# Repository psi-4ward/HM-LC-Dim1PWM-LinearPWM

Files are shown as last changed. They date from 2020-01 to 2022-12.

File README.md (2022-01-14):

# HM-LC-Dim1PWM-LinearPWM

**HomeMatic Aktor mit linearer PWM Ausgabe über Optokoppler zum Beschalten von PWM-Dim Eingängen.**

Es gibt eine ganze Reihe [Meanwell-Netzteile](https://www.meanwell-web.com/en-gb/led-drivers/all-technology/all-power-format/all-output-voltage-v/all-output-current-a/all-output-power-w/all-input-voltage-v/all-i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) mit PWM Eingang zum Dimmen welche über diese Schaltung angesteuert und in Homematic eingebunden werden können.

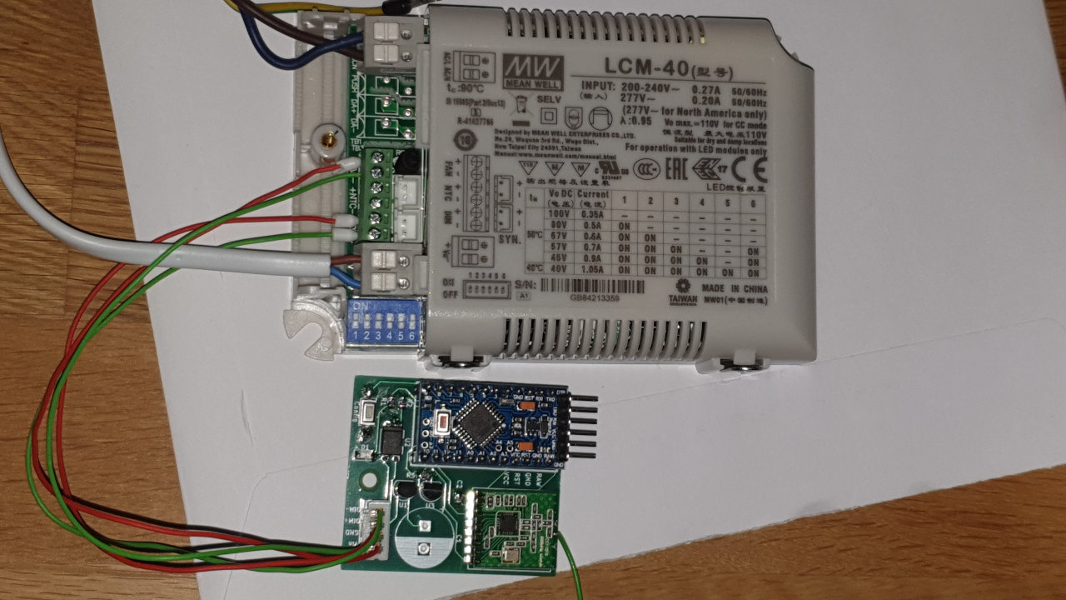
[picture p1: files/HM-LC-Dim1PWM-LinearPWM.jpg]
HM-LC-Dim1PWM-LinearPWM


Es ist darauf zu achten, dass man ein Netzteil mit **3 in 1 dimming** und **dimm-to-off** verwendet:
* 3 in 1: Dimmung über PWM, 0-10V und Potentiometer.
* dimm-to-off: Das Netzteil kann über den DIM-Eingang auch komplett ausgeschaltet werden.

Getestet wurde die Schaltung mit einem Meanwell LCM-40 Netzteil und 30W Konstantstrom-LED-Panel.
Das LCM-40 bietet zusätzlich einen 12V _FAN_ Anschluss worüber den die Schaltung mit Strom versorgt werden kann.

## Hardware

* Arduino Pro Mini 3.3V
* CC1101 Funkmodul
* C1: Elko 2200µF (optional)
* SMD Bauteile Größe 0805
  * C2: Kerko 100nF
  * C3: Kerko 100nF (für L78L05)
  * R1: 1,5kΩ
  * R2, R3: 280Ω
  * R4: 10kΩ
* D1: SMD LED Größe 1206
* SW1: SMD Taster 3x6x2,5mm
* U1: L78L05 Festspannungsregler Größe TO92 (optional)
* U2: Optokoppler PC817
* U3: DS18B20 Temperatursensor (optional)

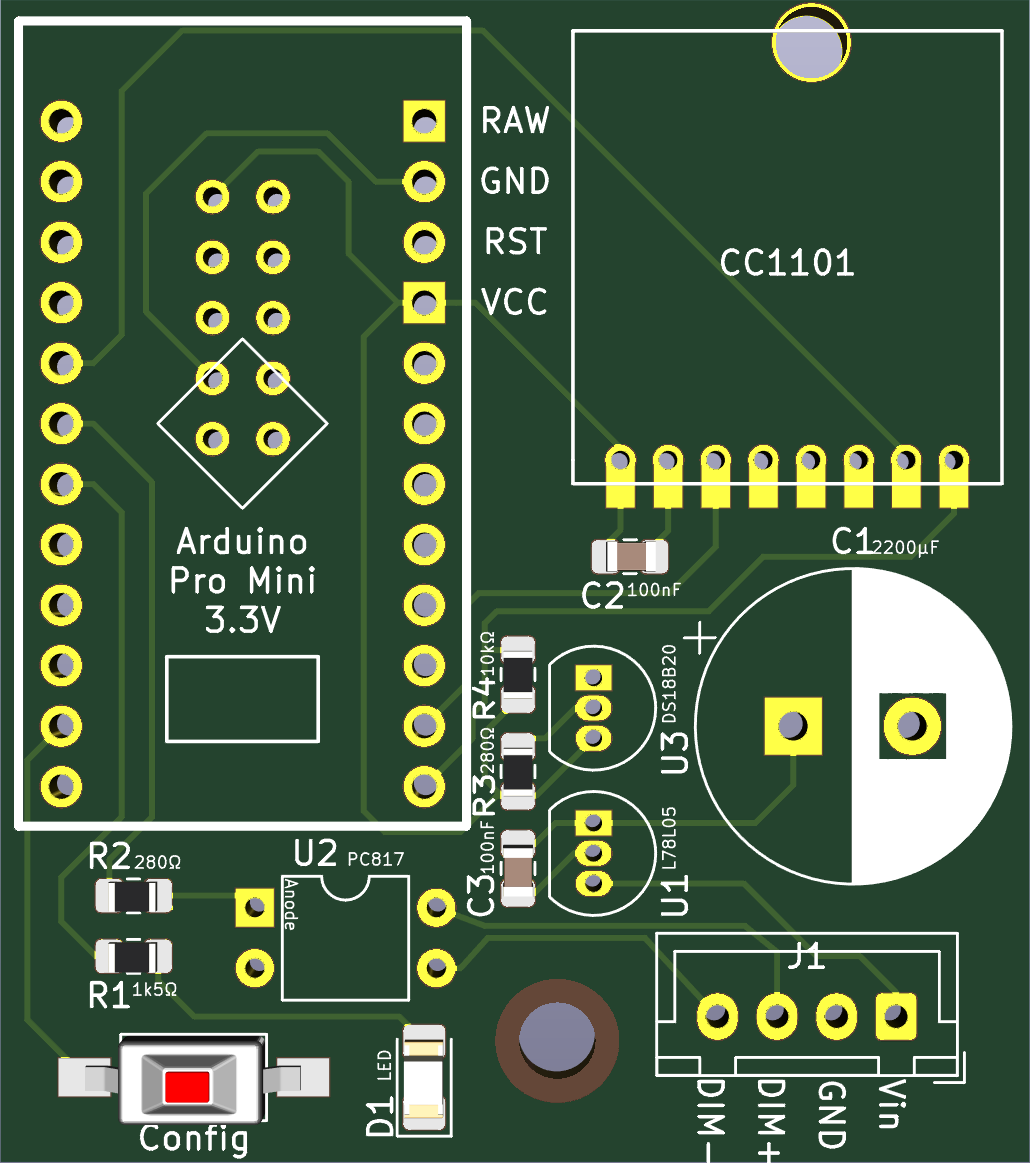
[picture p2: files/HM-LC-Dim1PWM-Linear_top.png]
PCB Top


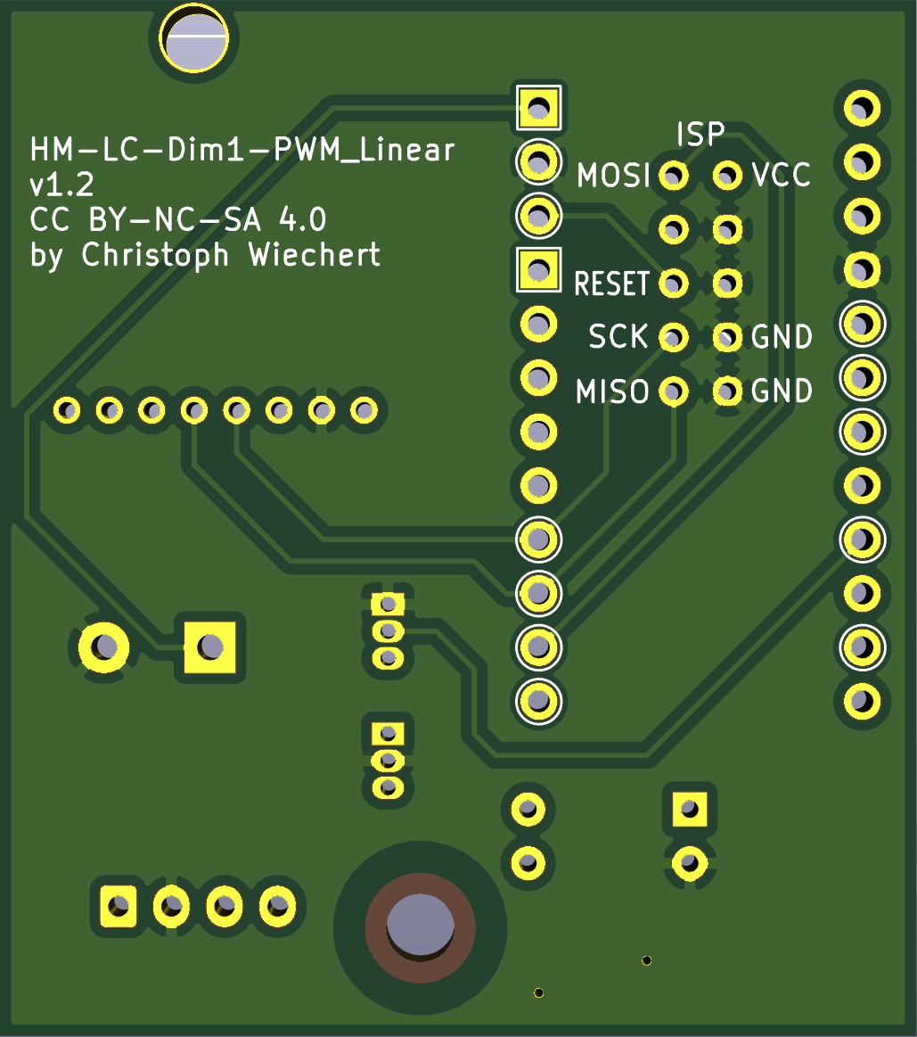
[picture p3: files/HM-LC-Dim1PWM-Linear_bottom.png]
PCB Bottom


## Sketch

Ein [Beispiel-Sketch](./HM-LC-Dim1PWM-LinearPWM.ino) ist im Repo hinterlegt.

Interssant ist die Instanziierung der PWM-Class:

```cpp
DimmerControl<HalType,DimmerType,PWM8<200,true,PWM_INVERSE> > control(sdev);
```

Wobei die Parameter des `PWM8`-Templates:
* `steps`: Anzahl Dimmer-Schritte
* `linear`: Flag um eine lineare Dimmerkurve zu erzeugen
* `inverse`: Dimmerkurve invertieren (nötig da Optokoppler)

**Es empfiehlt sich die Brown-Out-Detection des AVR zu deaktivieren um robuster gegen Spannungseinbrüche zu sein.**

## Case:

* [themaddin](https://www.prusaprinters.org/prints/118561-enclosure-for-homematic-diy-dimmer)  
  

## Changelog

### Version 1.2
* PullUp Widerstand R4 eingefügt 

### Version 1.1
* Markierungen ergänzt

## Lizenz

CreativeCommons BY-NC-SA 4.0

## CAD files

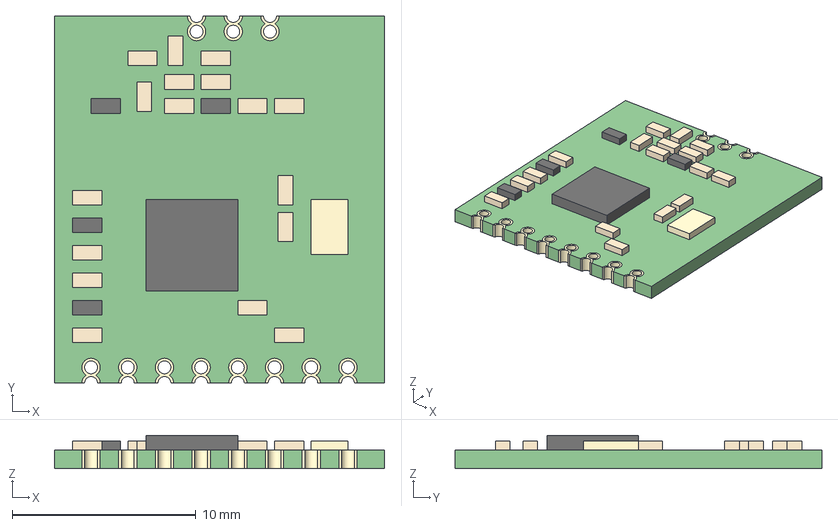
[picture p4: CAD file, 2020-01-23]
KiCad/CC1101_Module.step
18.0 x 20.0 x 1.80 mm
PCB
Parts
Pads

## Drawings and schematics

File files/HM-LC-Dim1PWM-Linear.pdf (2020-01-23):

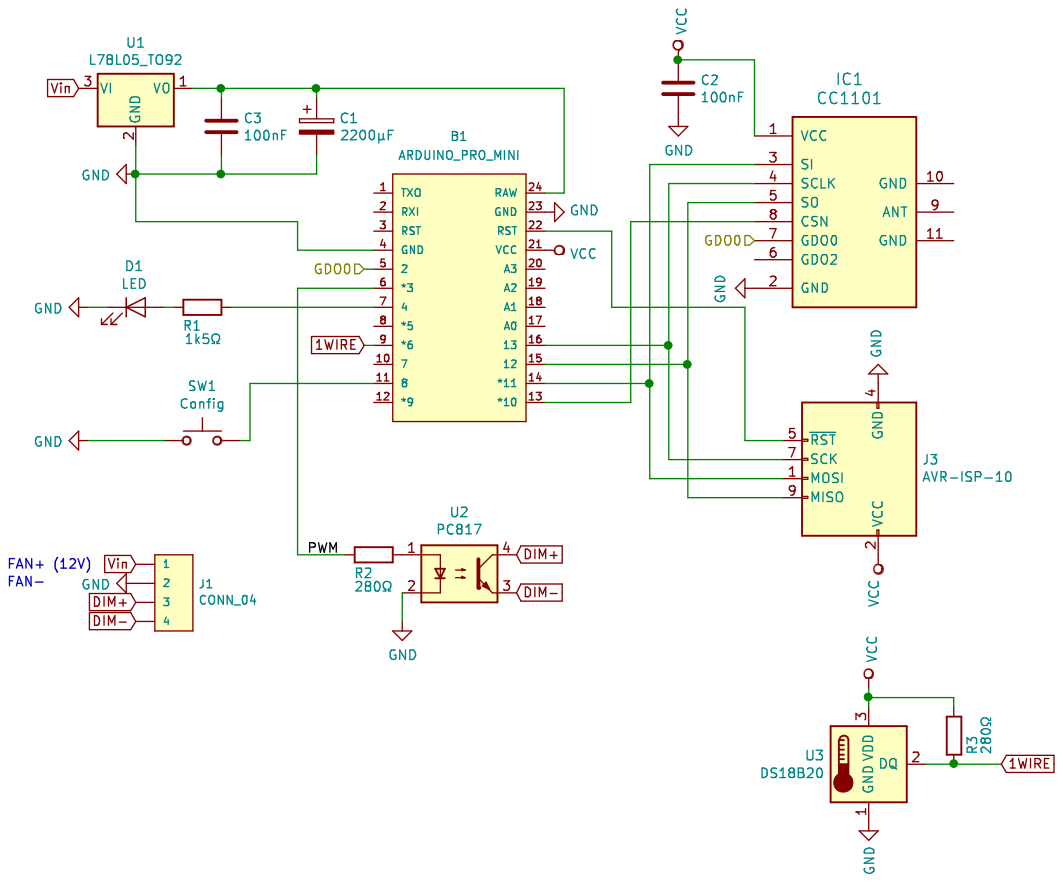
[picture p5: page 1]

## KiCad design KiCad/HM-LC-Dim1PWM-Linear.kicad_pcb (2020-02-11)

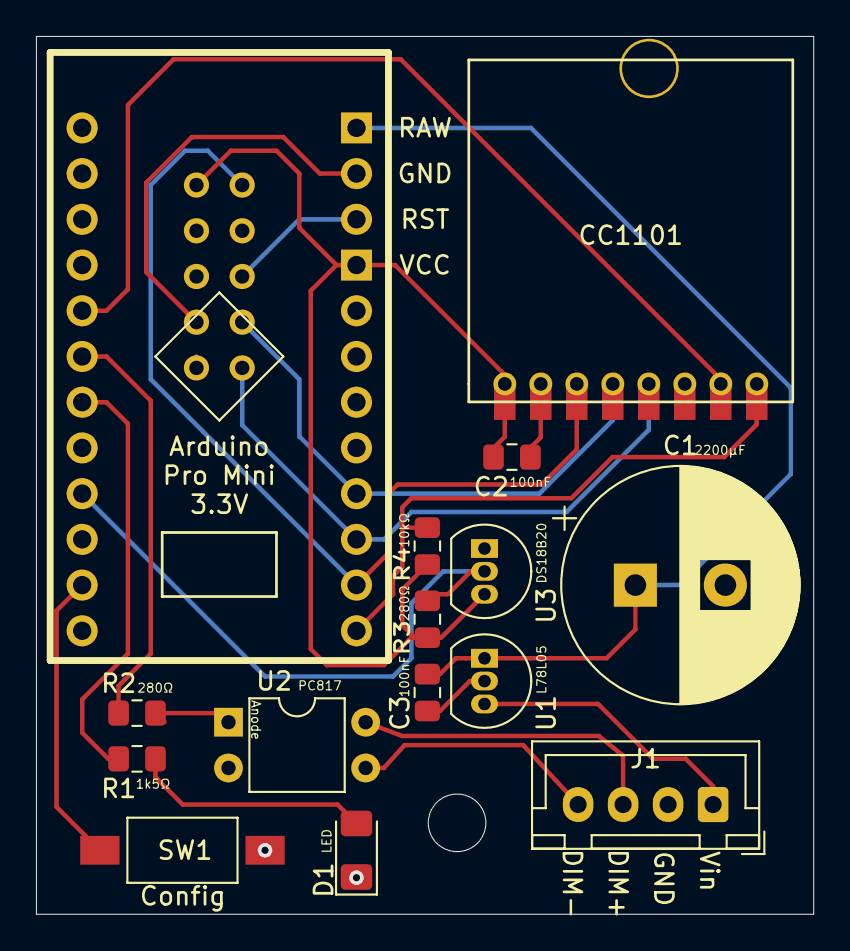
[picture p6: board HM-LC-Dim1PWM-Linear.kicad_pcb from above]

Board: 2 copper layers, 43.2 x 48.8 mm, 16 parts (1 on the bottom side), 18 nets.

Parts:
B1: ARDUINO_PRO_MINI; Arduino_Pro_Mini_wo_Ax
C1: 2200µF; CP_Radial_D13.0mm_P5.00mm
C2, C3: 100nF; C_0805_2012Metric_Pad1.15x1.40mm_HandSolder
D1: LED; LED_1206_3216Metric_Pad1.42x1.75mm_HandSolder
IC1: CC1101; CC1101_SMD_THT
J1: CONN_04; JST_XH_B4B-XH-A_1x04_P2.50mm_Vertical
J3: AVR-ISP-10; TestPoint_2x5Pads_Pitch2.54mm_Drill0.8mm
R1: 1k5Ω; R_0805_2012Metric_Pad1.15x1.40mm_HandSolder
R2, R3: 280Ω; R_0805_2012Metric_Pad1.15x1.40mm_HandSolder
R4: 10kΩ; R_0805_2012Metric_Pad1.15x1.40mm_HandSolder
SW1: Config; SW_SPST_FSMSM
U1: L78L05_TO92; TO-92_Inline
U2: PC817; DIP-4_W7.62mm
U3: DS18B20; TO-92_Inline

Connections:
1WIRE: B1.9, R3.1, U3.2
/GDO0: B1.5, IC1.7
/PWM: B1.6, R2.1
DIM+: J1.3, U2.4
DIM-: J1.4, U2.3
GND: B1.4, B1.23, C1.2, C2.2, C3.2, D1.1, IC1.2, J1.2, J3.4, J3.6, J3.8, J3.10, SW1.1, U1.2, U2.2, U3.1
unnamed: B1.7, R1.2
unnamed: B1.11, SW1.2
unnamed: B1.13, IC1.8, R4.1
unnamed: B1.14, IC1.3, J3.1
unnamed: B1.15, IC1.5, J3.9
unnamed: B1.16, IC1.4, J3.7
unnamed: B1.22, J3.5
unnamed: B1.24, C1.1, C3.1, U1.1
unnamed: D1.2, R1.1
unnamed: R2.2, U2.1
VCC: B1.21, C2.1, IC1.1, J3.2, R3.2, R4.2, U3.3
Vin: J1.1, U1.3

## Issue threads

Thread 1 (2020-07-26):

Coding Problems

mwpost, 2020-07-26:
Hallo psi,

ich bekomme den Beispiel-Sketch leider nicht kompiliert. Ich benutze einen Arduino Pro Mini 3,3V, 8MHz und die Arduino Entwicklungsumgebung 1.8.12. Ich habe die Bibliothek Asksinpp-V4 und alternativ den Master-Branch probiert. Leider bricht die Kompilierung immer mit folgenden Fehlern ab:
"
In file included from C:\Mein_Verzeichnis\Documents\Arduino\libraries\AskSinPP-master/Dimmer.h:11:0,

                 from C:\Mein_Verzeichnis\AppData\Local\Temp\arduino_modified_sketch_568111\HM-LC-Dim1PWM-CV.ino:14:

C:\Mein_Verzeichnis\Documents\Arduino\libraries\AskSinPP-master/actors/PWM.h: In member function 'void as::PWM8<STEPS, LINEAR, INVERSE>::sendData(byte, byte)':

C:\Mein_Verzeichnis\Documents\Arduino\libraries\AskSinPP-master/actors/PWM.h:57:28: error: 'CHIP_ADDR' was not declared in this scope

     Wire.beginTransmission(CHIP_ADDR >> 1);

                            ^~~~~~~~~

C:\Mein_Verzeichnis\Documents\Arduino\libraries\AskSinPP-master/actors/PWM.h:57:28: note: suggested alternative: '_SFR_ADDR'

     Wire.beginTransmission(CHIP_ADDR >> 1);

                            ^~~~~~~~~

                            _SFR_ADDR

C:\Mein_Verzeichnis\Documents\Arduino\libraries\AskSinPP-master/actors/PWM.h: In member function 'void as::PWM99<STEPS, LINEAR, INVERSE>::set(uint8_t)':

C:\Mein_Verzeichnis\Documents\Arduino\libraries\AskSinPP-master/actors/PWM.h:107:11: error: 'wiper0writeAddr' was not declared in this scope

  sendData(wiper0writeAddr, brightness);

           ^~~~~~~~~~~~~~~

exit status 1
Fehler beim Kompilieren für das Board Arduino Pro or Pro Mini.
"

Hast Du einen Tipp für mich?

Besten Dank für die Unterstützung,
mwpost

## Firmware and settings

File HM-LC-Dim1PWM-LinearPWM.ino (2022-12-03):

//- -----------------------------------------------------------------------------------------------------------------------
// AskSin++
// 2016-10-31 papa Creative Commons - http://creativecommons.org/licenses/by-nc-sa/3.0/de/
//- -----------------------------------------------------------------------------------------------------------------------

// define this to read the device id, serial and device type from bootloader section
// #define USE_OTA_BOOTLOADER

#define EI_NOTEXTERNAL
#include <Wire.h>
#include <EnableInterrupt.h>
#include <AskSinPP.h>
#include <sensors/Ds18b20.h>
#include <Dimmer.h>


// we use a Pro Mini
#define LED_PIN 4
#define DIMMER_PIN 3
#define DS18B20_PIN 6
#define CONFIG_BUTTON_PIN 8

#define PWM_INVERSE true


// number of available peers per channel
#define PEERS_PER_CHANNEL 4

// all library classes are placed in the namespace 'as'
using namespace as;

// define all device properties
const struct DeviceInfo PROGMEM devinfo = {
    {0x11,0x12,0x5A},       // Device ID
    "konstant22",           // Device Serial
    {0x00,0x67},            // Device Model
    0x25,                   // Firmware Version
    as::DeviceType::Dimmer, // Device Type
    {0x01,0x00}             // Info Bytes
};

/**
 * Configure the used hardware
 */
typedef AvrSPI<10,11,12,13> SPIType;
typedef Radio<SPIType,2> RadioType;
typedef StatusLed<LED_PIN> LedType;
typedef AskSin<LedType,NoBattery,RadioType> HalType;
typedef DimmerChannel<HalType,PEERS_PER_CHANNEL> ChannelType;
typedef DimmerDevice<HalType,ChannelType,3,3> DimmerType;

HalType hal;
DimmerType sdev(devinfo,0x20);
DimmerControl<HalType,DimmerType,PWM8<200,true,PWM_INVERSE> > control(sdev);
ConfigToggleButton<DimmerType> cfgBtn(sdev);

class TempSens : public Alarm {
  Ds18b20  temp;
  OneWire  ow;
  bool     measure;
public:
  TempSens () : Alarm(0), ow(DS18B20_PIN), measure(false) {}
  virtual ~TempSens () {}

  void init () {
    Ds18b20::init(ow, &temp, 1);
    if( temp.present()==true ) {
      set(seconds2ticks(15));
      sysclock.add(*this);
    } else {
      DPRINTLN("WARN: No Tempsensor found!");
    }
  }

  virtual void trigger (AlarmClock& clock) {
    if( measure == false ) {
      temp.convert();
      set(millis2ticks(800));
    }
    else {
      temp.read();
      DPRINT("Temp: ");DDECLN(temp.temperature());
      control.setTemperature(temp.temperature());
      set(seconds2ticks(60));
    }
    measure = !measure;
    clock.add(*this);
  }
};
TempSens tempsensor;

void setup () {
  DINIT(57600,ASKSIN_PLUS_PLUS_IDENTIFIER);
  Wire.begin();
  if( control.init(hal,DIMMER_PIN) ) {
    // first init - setup connection between config button and first channel
    sdev.channel(1).peer(cfgBtn.peer());
  }
  buttonISR(cfgBtn,CONFIG_BUTTON_PIN);

  tempsensor.init();
  sdev.initDone();
  // sdev.led().invert(true);
  DDEVINFO(sdev);

  if(PWM_INVERSE) {
    // Dimm to off after boot
    sdev.channel(1).set(200, 0b01000001, 0xffff);
  }
}

void loop() {
  hal.runready();
  sdev.pollRadio();
}

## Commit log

2020-01-24 Add R4 PullUp for CC1101
    [HM-LC-Dim1PWM-Linear-B_Cu.gbl, HM-LC-Dim1PWM-Linear-B_Mask.gbs, HM-LC-Dim1PWM-Linear-B_SilkS.gbo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]
2020-02-11 Add image
    [HM-LC-Dim1PWM-Linear.kicad_pcb]
2022-01-14 Add Case link

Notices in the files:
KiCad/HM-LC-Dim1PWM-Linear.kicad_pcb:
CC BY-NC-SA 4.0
